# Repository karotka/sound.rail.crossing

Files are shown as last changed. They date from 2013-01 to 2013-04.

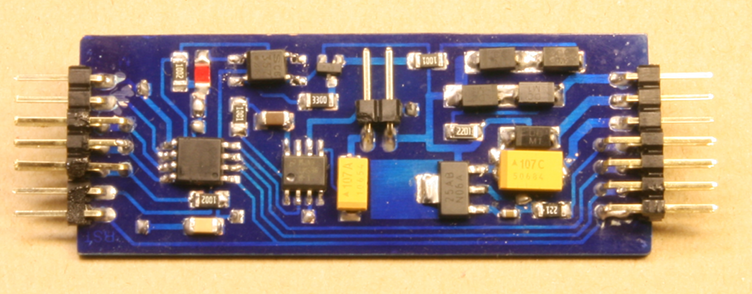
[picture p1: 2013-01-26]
pcb/board.photo.png

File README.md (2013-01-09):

This is the project of sound railcrossing for DCC railroad. It is based on the ATTINY85 microprocesor. It contains software for ATTINY, circuit and PCB. You can use as DCC Compatible Block Occupancy Detector on isolation rail, switching the railcrossing lights with sound and as servo driver for railway crossing barriers.
It can be use in 2 modes:

1. DCC Compatible Block Occupancy Detector
2. In switch ON/OFF mode

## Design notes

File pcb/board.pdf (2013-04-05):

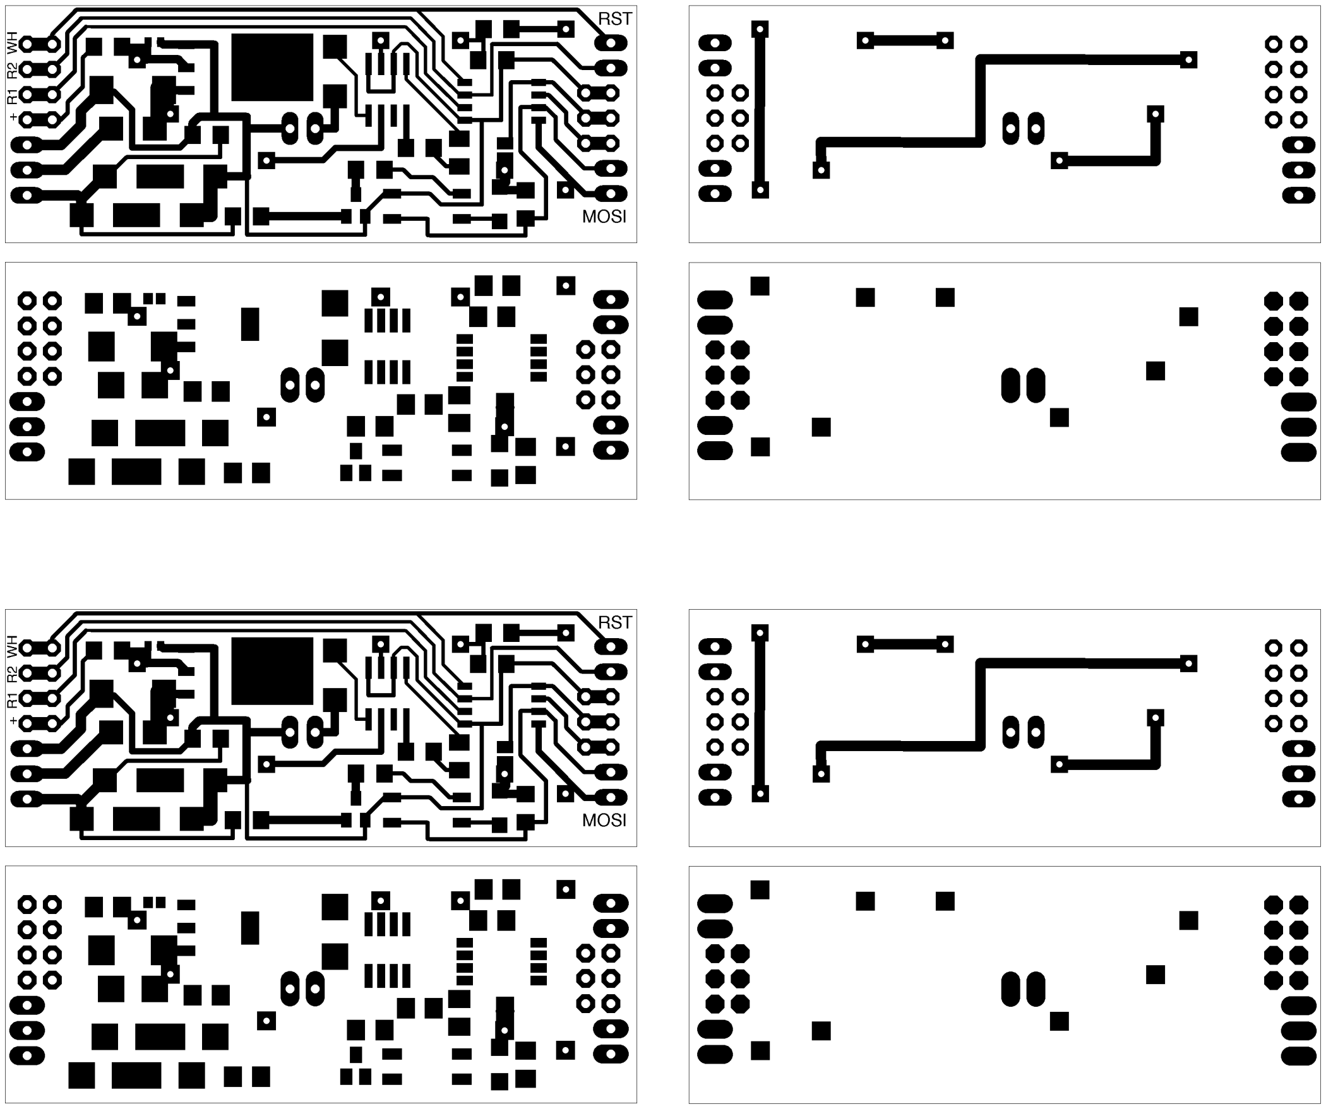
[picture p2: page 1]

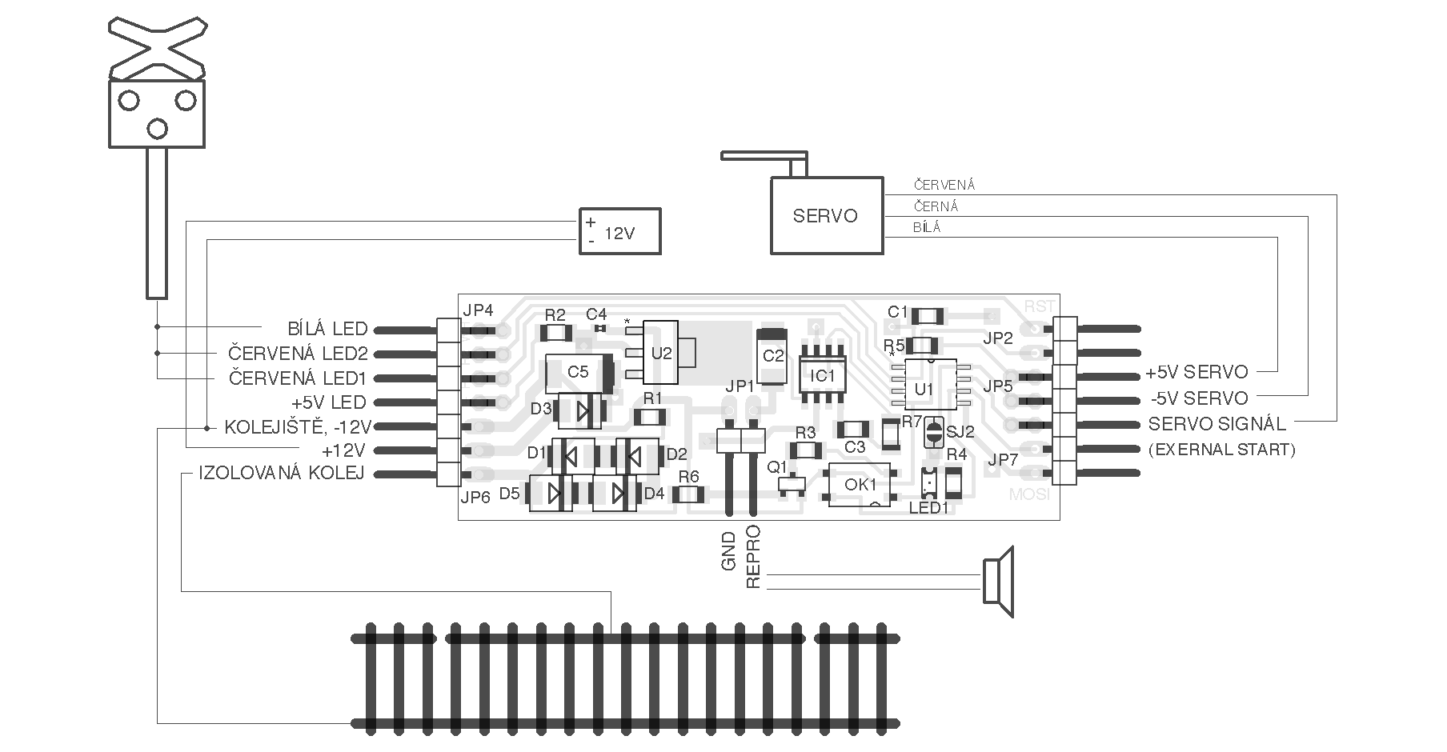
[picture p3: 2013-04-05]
pcb/board.png

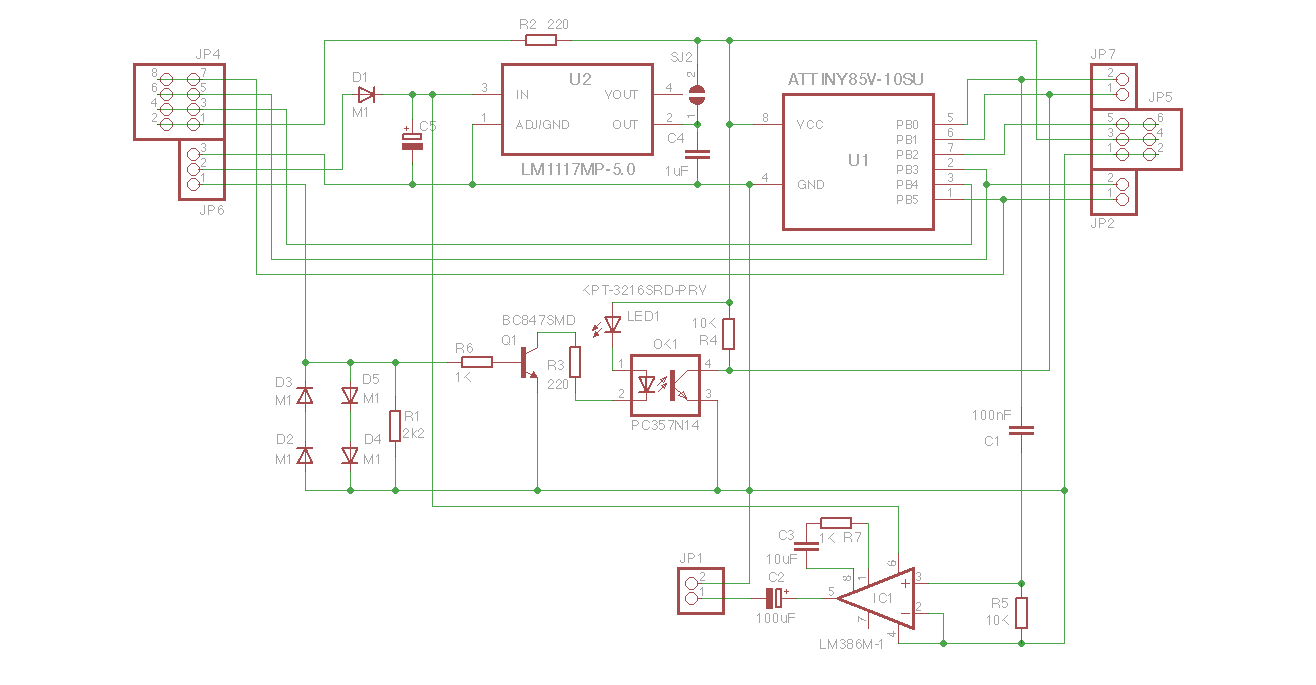
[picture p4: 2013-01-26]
pcb/circuit.png

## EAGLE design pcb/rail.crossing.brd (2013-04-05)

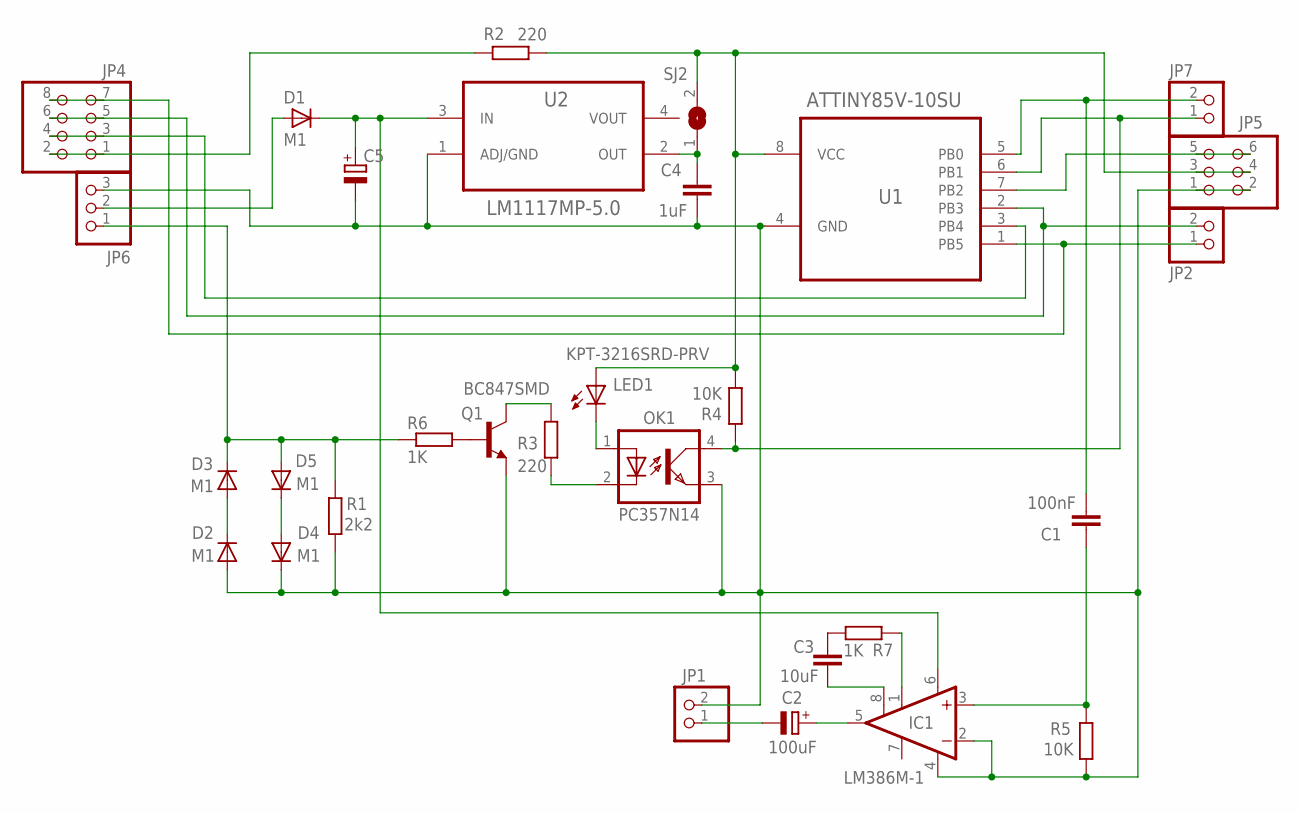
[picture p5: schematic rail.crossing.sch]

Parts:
C1: 100nF; C1206
C2: 100uF; SMC_C
C3: 10uF; C1206
C4: 1uF; C0402
C5: CPOL-EUSMCD; SMC_D
D1, D2, D3, D4, D5: M1; SMB
IC1: LM386M-1; SO08
JP1, JP2, JP7: PINHD-1X2/90; 1X02/90
JP4: PINHD-2X4/90; 2X04/90
JP5: PINHD-2X3/90; 2X03/90
JP6: PINHD-1X3/90; 1X03/90
LED1: KPT-3216SRD-PRV; SML1206
OK1: PC357N14; SMD4
Q1: BC847SMD; SOT23
R1: 2k2; R1206
R2, R3: 220; R1206
R4, R5: 10K; R1206
R6: 1K; R1206
R7: 1K; M1206
SJ2: SJ
U1: ATTINY85V-10SU; SOIC127P798X216-8N
U2: LM1117MP-5.0; SOT230P696X180-4N

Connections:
220: LED1.C, OK1.1 (A)
JP1: D3.C, D5.A, JP6.1, R1.1, R6.1
JP2: C4.2, D2.A, D4.C, IC1.2 (-IN), IC1.4 (GND), JP1.2, JP5.1, JP5.2, JP6.3, OK1.3 (EMIT), Q1.2 (E), R1.2, R5.2, U1.4 (GND), U2.1 (ADJ/GND)
unnamed: C2.-, JP1.1
unnamed: C3.1, R7.1
unnamed: C3.2, IC1.8 (GAIN)
unnamed: D2.C, D3.A
unnamed: D4.A, D5.C
unnamed: Q1.1 (B), R6.2
unnamed: Q1.3 (C), R3.1
unnamed: C2.+, IC1.5 (OUT)
unnamed: OK1.2 (C), R3.2
unnamed: JP5.5, JP5.6, U1.7 (PB2)
unnamed: C1.1, JP7.2, U1.5 (PB0)
unnamed: JP4.1, JP4.2, R2.1
unnamed: JP7.1, OK1.4 (COL), R4.1, U1.6 (PB1)
unnamed: JP5.3, JP5.4, LED1.A, R2.2, R4.2, SJ2.2, U1.8 (VCC)
unnamed: IC1.1 (GAIN), R7.2
unnamed: C1.2, IC1.3 (+IN), R5.1
unnamed: C4.1, SJ2.1, U2.2 (OUT)
unnamed: D1.A, JP6.2
unnamed: C5.+, D1.C, IC1.6 (VS), U2.3 (IN)
RED1: JP2.2, JP4.5, JP4.6, U1.2 (PB3)
RED2: JP4.3, JP4.4, U1.3 (PB4)
WHITE: JP2.1, JP4.7, JP4.8, U1.1 (PB5)

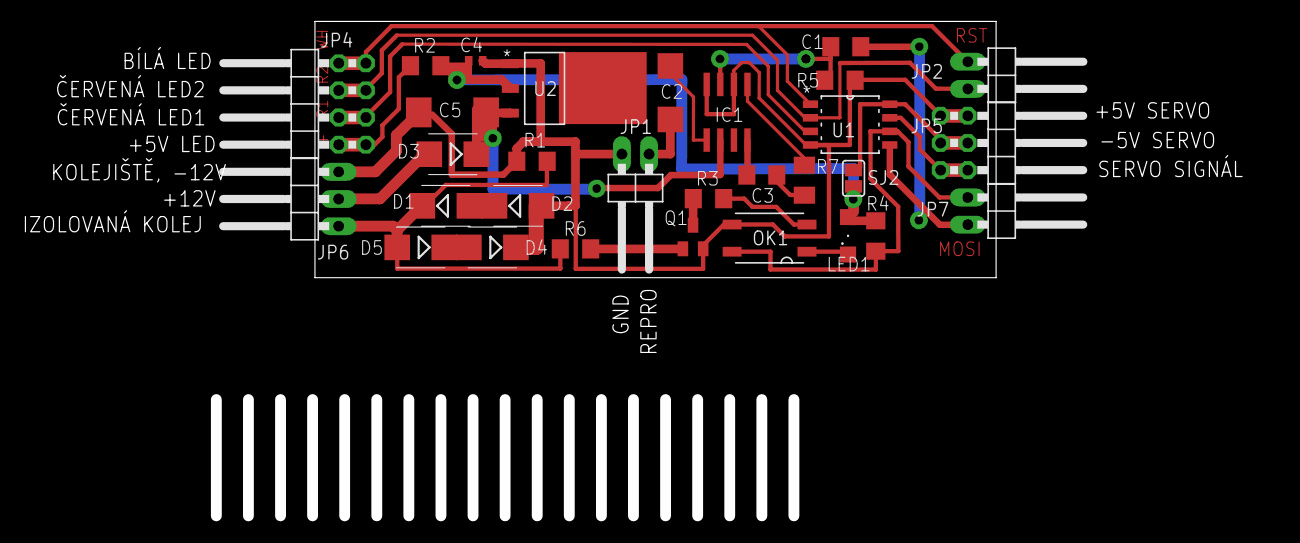
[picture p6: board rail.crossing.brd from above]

Board: 2 copper layers, 63.7 x 24.0 mm, 30 parts (0 on the bottom side), 25 nets.

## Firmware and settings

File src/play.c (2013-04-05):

#define F_CPU 8000000UL /** Lfuse (ATtiny85) must be set on 0xE2 */
#define DELAY 1000 /** Delay fof hold in run state, bypass for disconnecting from rails */
#define EXTERNALINT /** Use externall interrupt for change state or button */

/**
* White LED is connected to PB5 (Externall reset pin)
* For white LED enable, you need to disable externall reset
* in HVSP mode (set Fuse High Byte)
* RSTDISBL = 0 (programmed)
*
* avrdude -P usb -p t85 -c dragon_hvsp -t
* w hfuse 0 0x5f
**/

#include <stdint.h>
#include <avr/io.h>
#include <avr/pgmspace.h>
#include <util/delay.h>
#include <avr/interrupt.h>
#include "pcm_sample.h"

volatile uint16_t sample;
volatile unsigned int count0;
volatile unsigned int count2;
volatile unsigned int count3;
volatile unsigned int servoPos;
volatile unsigned int run;

volatile unsigned int w;
volatile unsigned int pos;

unsigned int servoMin = 568; // 570 = 1ms
unsigned int servoMax = 605; // 600 = 2ms


unsigned int debounce(volatile uint8_t *port, uint8_t pin) {
    if (!(*port & (1 << pin))) {
        _delay_ms(80);
        if ( *port & (1 << pin) ) {
            _delay_ms(80);
            return 1;
        }
    }
    return 0;
}

/**
* Set start attributes
*/
void start() {
    TCCR0A = (1 << COM0A1) | (1 << COM0A0) | (1 << WGM01) | (1 << WGM00);
    TCCR0B = (1 < WGM02) | (1 << CS00);

    TCCR1 |= (1 << CS10);
    PORTB &= ~(1 << PB3);
    PORTB |= (1 << PB4);
    sample = 0;
    run = 1;
}

/**
* Set stop attributes
*/
void stop() {
    TCCR0A = 0;
    TCCR0B = (1 < WGM02) | (1 << CS00);// | (1 << CS02);

    TCCR1 |= (1 << CS10);
    PORTB |= (1 << PB3);
    PORTB |= (1 << PB4);
    OCR0A = 0;
    run = 0;
}

/**
* Chip init attributes
*/
void cpuInit(void) {
    DDRB = 0x00;
    /** output pins */
    DDRB |= (1 << PB0) | (1 << PB2) | (1 << PB3) | (1 << PB4) | (1 << PB5);
    /** input pins */
    DDRB &= ~(1 << PB1); /* pin PB1 input */

    /** timer 0 and pwm for playing sound */
    TCCR0A = (1 << COM0A1) | (1 << COM0A0) | (1 << WGM01) | (1 << WGM00);
    //TCCR0B = (1 < WGM02) | (1 << CS00);
    TCCR0B = (1 < WGM02) | (1 << CS00) | (1 << CS02);
    OCR0A = 0;
    TIMSK |= (1 << TOIE0);

    /** timer 1 servo controler */
    TCCR1 |= (1 << CTC1);// | (1 << CS10);
    OCR1A = 4;
    TCNT1 = 0;
    TIMSK |= (1 << OCIE1A);
    //TCCR1 &= ~(1 << CS10);

#ifdef EXTERNALINT
    /** externall interupt change from INT0 on PC1 (PB1)
     * for better circuit and servo connection */
    MCUCR |= (1 << ISC01);
    GIMSK |= (1 << PCIE);
    PCMSK |= (1 << PCINT1);
#endif

    servoPos = servoMin;

    count0 = 0;
    count2 = 0;
    count3 = DELAY;
    run = 0;

    /** enable all interrupts */
    sei();
}

/**
* Externall interrupt on PCINT0
*/
ISR(PCINT0_vect) {
    // simply set this counter
    count3 = DELAY;
}

/**
* Timer 1 overflow, servo driver
*/
ISR(TIMER1_COMPA_vect) {
    count2++;
    // 630 = 20 ms
    if (count2 == 630) {
        count2 = 0;

        if (run && servoPos < servoMax) {
            servoPos++;
        }

        if (!run && servoPos > servoMin) {
            servoPos--;
        }

        // servo is up or down, TIMER1 stop
        if (servoPos == servoMin || servoPos == servoMax) {
            TCCR1 &= ~(1 << CS10);
        }
    }

    if (count2 > servoPos) {
        PORTB |= 1 << PB2;
    } else {
        PORTB &= ~(1 << PB2);
    }
}

/**
* Timer 0 overflow for playing sound
*/
ISR(TIMER0_OVF_vect) {

    count0++;
    if (run) {
        if (count0 == 4) {

            count0 = 0;
            OCR0A = pgm_read_byte(&pcm_samples[sample++]);

            if(sample > pcm_length) {
                sample = 0;
                PORTB ^= 1 << PB3;
                PORTB ^= 1 << PB4;
            }
            if (sample == pcm_length / 2) {
                PORTB ^= 1 << PB3;
                PORTB ^= 1 << PB4;
            }
        }
    } else {
        /*
        if (count0 > 20500 && count0 < 24000) {
            if ((count0 - 20000) % 50 == 0) {
                w = (count0 - 20000) / 50;
                pos = 0;
            } else {
                if (w > pos) {
                    PORTB &= ~(1 << PB5);
                } else {
                    PORTB |= 1 << PB5;
                }
                pos++;
            }
        }
        if (count0 > 46000 && count0 < 48000) {
            if ((count0 - 46000) % 30 == 0) {
                w = (count0 - 46000) / 30;
                pos = 0;
            } else {
                if (w > pos) {
                    PORTB |= 1 << PB5;
                } else {
                    PORTB &= ~(1 << PB5);
                }
                pos++;
            }
        }
        */

        if (count0 == 15000) {
            PORTB &= ~(1 << PB5);
        } else
        if (count0 == 30000) {
            PORTB |= 1 << PB5;
            count0 = 0;
        }
    }
}

int main(void) {
    cpuInit();

    PORTB |= (1 << PB3);
    PORTB |= (1 << PB4);
    PORTB |= (1 << PB5);

    while(1) {

#ifdef EXTERNALINT

        // wait and decreese the counter
        _delay_ms(1);
        count3--;

        if (count3 < 1) {
            count3 = 1;
            if (run) {
                stop();
            }
        } else {
            if (!run) {
                start();
            }
        }
#else
        if (debounce(&PINB, PB1)) {
            if (!run) {
                start();
            } else {
                stop();
            }
        }
#endif
    }
}

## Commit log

2013-01-09 Add res and pcb
2013-01-13 Add board
2013-01-18 add pcb board and circuit
    [rail.crossing.brd, rail.crossing.sch]
2013-01-18 mv schema to circuit
2013-01-18 set pwm to zero after stop
2013-01-26 add new board witch mask
    [rail.crossing.brd, rail.crossing.sch]
2013-04-05 Disable pwm
    [rail.crossing.brd]
